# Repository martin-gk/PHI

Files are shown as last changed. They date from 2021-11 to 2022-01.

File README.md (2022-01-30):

# PHI - Plant Human Interface

Project for my bachelor thesis at FH JOANNEUM - Mobile Software Development

## Introduction

The Plant Human Interface project aims to bring the user closer to his houseplants. With the help of low entry hardware components like Arduino and the IOT, I plan to enhance myself to be able to feel when my houseplants needs to be watered.

## Motivation

Cyborgs have inspired the imagination of humans since the invention of machines. From dark dystopian futures like the Terminator or the BORG from Star Trek to helpful individuals like Inspector Gadget.
Our technological advancements have moved these fantasies into the realm of reality. Although one could argue that people with prosthetic limbs count as cyborgs, it does not satisfy this SciFi notion we have when we talk about cyborgs.
The following examples do however.

- [Neil Harbisson](https://en.wikipedia.org/wiki/Neil_Harbisson) with his [Eyeborg](https://en.wikipedia.org/wiki/Eyeborg)
- [Moon Ribas](https://en.wikipedia.org/wiki/Moon_Ribas) with her seismic sense
- The [North Sense](https://www.cyborgnest.net/northsense) from [Cyborg Nest](https://www.cyborgnest.net/) and their new product [Sentero](https://www.cyborgnest.net/sentero)
- [Kevin Warwick](https://en.wikipedia.org/wiki/Kevin_Warwick) and his countless experiments
- Everyone involved in the [Dangerous Things](https://dangerousthings.com/) community
- [Manel de Aguas](https://en.wikipedia.org/wiki/Manel_Mu%C3%B1oz) with his weather fins
- and many more

I myself am very fascinated by cyborgs and in awe of the technological possibilities at our hands. Therefore my project tries to make me a cyborg by enhancing my abilities and connecting me to a different organism - my houseplant -.

## Structure

The project is structured in five parts

- Plant
  - documentation for the microcontroller and sensors reading the plants vitals
  - how to assemble everything and the code needed to read the sensor values.
- Human
  - documentation on the hardware for the wearable
  - the code necessary to write data onto the e-paper display
  - the code necessary to use the vibrating motor
- Cloud
  - documentation on how to connect the devices to the IoT cloud
  - exemplary code on the auto generated sketches by the arduino IoT cloud
- Power
  - Information on different power sources as well as safety information
  - Recommendation on using a power bank
- Case
  - files for 3d printing a case

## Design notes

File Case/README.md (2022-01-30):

# 3d Case

If you have built the project so far, you may want <br>
to have a case in order to wear it comfortably. <br>
The files in this directory are always the same model, <br>
I just decided to export it in different formats <br>
in order to make it accessible to a multitude of 3d printers.<br>
<br>
As for the filament I used PA, but this is not required, please <br> just use whatever you have at hand.<br>
<br>
The small slit in the back of the case is for the vibration motor to <br>
slid through in order to have skin contact. <br>
As a recommendation I secured the ESP32 board via screws to the case.
After printing there is a small modification that I recommend you do.<br>
<br>
The red circle in the following picture shows where I drilled a hole <br>
on the side to pass the cables that go into the power bank through. <br><br>

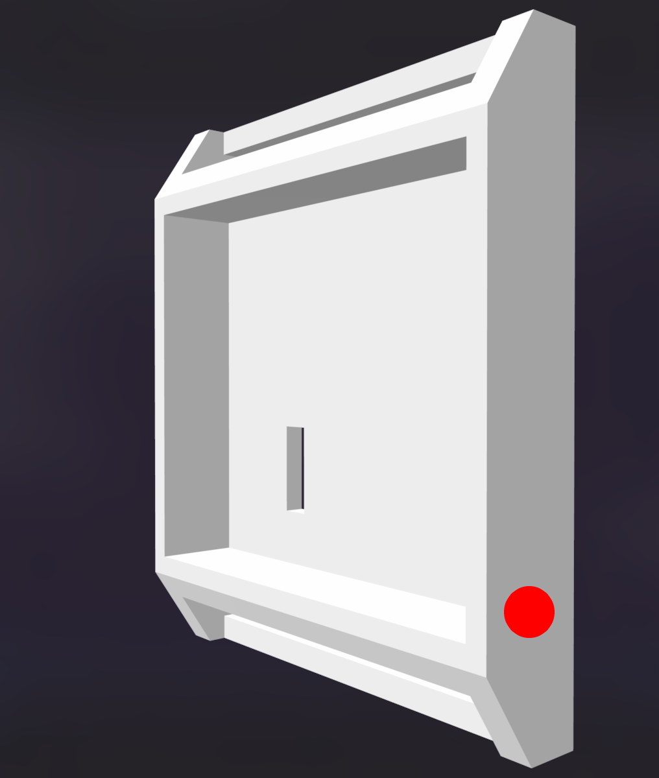
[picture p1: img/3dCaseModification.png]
3dcasemodification


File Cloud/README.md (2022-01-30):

# Cloud

## First Steps

The Arduino IoT Cloud is a service that is provided by Arduino. <br>
It features a free and a paid version. For the scope of this project the free version is enough <br>
but a registration is still necessary.

## Connect your hardware to the cloud

I will never be able to write a better step by step guide as Arduino themselves so please enjoy the wonderfully <br>
created tutorial by Arduino. <br>

- [Getting started with the Arduino IoT cloud](https://docs.arduino.cc/cloud/iot-cloud/tutorials/iot-cloud-getting-started)

When you have reached step 5 you will need to create the following variables

- humidity: float; Read and Write
- light: int; Read and Write
- temperature: float; Read and Write
- moisture: int; Read and Write

Once you have connected one device to the cloud you will want to sync the variables to the second device. <br>
This step is documented [here](https://docs.arduino.cc/cloud/iot-cloud/tutorials/device-to-device) in step 5.<br>
The tutorial features an explanation for arduino boards as well as for third party boards like the ESP32 for our wearable. <br>
Once you have completed all the steps the cloud will have generated a thingProperties.h sketch that your hardware needs in order to <br> communicate with the cloud. Exemplary sketches can be found in the directories inside this directory. <br>
The cloud will also generate a arduino_secrets.h file with your network login data. This is not included in this documentation.

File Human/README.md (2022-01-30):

# Human

## Hardware

- LILYGO TTGO E-Paper Watch
- T-U2T Downloader

## First Steps

As this is a complete system with the e-ink display and the vibrating motor already built in all you have to do is <br>
check if everything you ordered has been shipped. <br>
Especially the T-U2T Downloader as this is necessary to connect the board to your computer.

## Connecting to your computer

Connecting to your computer is simple. Just plugin the T-U2T Downloader into the board and then both via usb to your computer. <br>
For communication it may be that you will need to download drivers. <br>
Depending on which T-U2T Downloader you get the drivers are the following. <br>

- [cp210x](https://www.silabs.com/developers/usb-to-uart-bridge-vcp-drivers)
- [ch340k](http://wch-ic.com/products/CH340.html)
- [ch9102](http://www.wch.cn/products/CH9102.html) website is in chinese
- I found that on my newer windows machine the communication worked out of the box, without the need to install drivers

Depending on your previous experience in microcontroller you may also need to install the esp32 board to your Arduino IDE.<br>
Please refer to the following step by step guide on how to install esp32.

- [esp32 installation guide](https://randomnerdtutorials.com/installing-the-esp32-board-in-arduino-ide-windows-instructions/)

## Adding your hardware to the Arduino IoT cloud

This step will be covered in the cloud subsection of the project so please refer to it.

## Code

You will need to install the following extra libraries before you can compile your code.

- [Adafruit GFX](https://github.com/adafruit/Adafruit-GFX-Library) this library is easier to install with the built in library manager in the IDE
- [GxEPD lewisxhe fork](https://github.com/lewisxhe/GxEPD) Please note that you will need this fork. Download it as zip and import the zip file via your library manager.
- [u8g2 by Oli Kraus](https://github.com/olikraus/u8g2) This library can also be installed from within the library manager

The complete code is in this directory, everything of importance has been commented.<br>
Please don't forget that you will also need the thingProperties.h and the arduino_secrets.h generated by the arduino cloud in the <br> same directory for the project to work.

## Troubleshooting

IF you encounter the following error on compile

```
int16_t GxFont_GFX::getUTF8Width(const char*)' cannot be overloaded
error: with 'int16_t GxFont_GFX::getUTF8Width(const char*)
```

It is an error within the GxEPD library. You will need to go into the src code of the library and alter the following two files:

- GxFont_GFX.cpp: comment or delete line 68-71 and 285-288
- GxFont_GFX.h: comment or delete line 45 and 77

The issue is a merging error that has already been reported on the respective github repository.

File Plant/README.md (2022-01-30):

# Plant

## Hardware

- Arduino IOT Carrier
- Arduino MKR WIFI 1010
- Capacitive Soil Moisture Sensor v1.2

## First Step

We will be building this part of the project within the Arduino environment and with the Arduino IOT Cloud, so you will need to create an account on [arduino.cc](https://www.arduino.cc/).

After you have your account registered you need to connect the Arduino MKR WIFI 1010 onto the IOT Carrier.
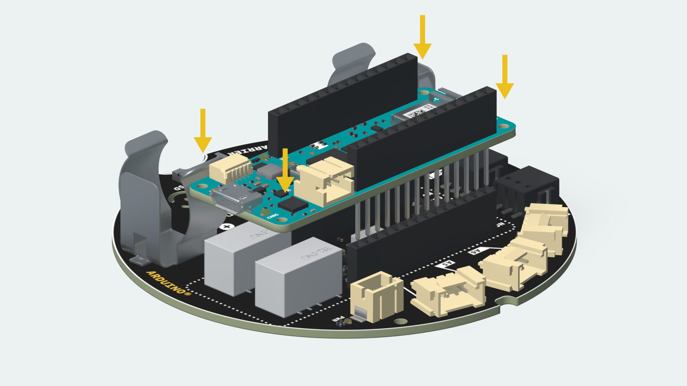
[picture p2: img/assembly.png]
assembly
[^1]
[^1]: Image taken from https://opla.arduino.cc/opla/module/carrier/lesson/discovering-the-mkr-iot-carrier
<br>

Please visit the [oplà kit website](https://opla.arduino.cc/opla/module/carrier/lesson/discovering-the-mkr-iot-carrier) for an in depth tutorial.

## Connecting to your computer

In order to be able to upload your first sketch onto your board, you will need to connect your board via USB to your computer.
You will need to download the [Arduino Create Agent](https://create.arduino.cc/getting-started/plugin/welcome) in order to recognize the Arduino boards and to read and write data from serial monitor.

You should be able to just use the Arduino Browser IDE but I also recommend downloading the standalone IDE. <br>
For example if you need to update the firmware, this will need to be done in the standalone IDE. <br>

## Adding your hardware to the Arduino IoT cloud

This step will be covered in the cloud subsection of the project so please refer to it.

## Code

The complete code is in this directory, everything of importance has been commented.
With your carrier connected via USB upload the sketch onto it. <br>
Once you have uploaded for the first time, the carrier supports Over the air uploads. <br>
This means you don't need to plug it in for updates, its enough to be in the same WiFi network.
<br>
Please don't forget that you will also need the thingProperties.h and the arduino_secrets.h generated by the arduino cloud in the <br> same directory for the project to work.

## Troubleshooting

If you get this error while trying to install your board to the cloud

```
MkrWifi1010 cannot connect to cloud
ArduinoIoTCloudTCP::handle_ConnectMqttBroker could not connect to mqtts-sa.iot.arduino.cc:8883
```

The firmware on your board is not up to date. <br>
Please refer to the following instruction to update the firmware. Be aware that you will need the freely available <br>
Arduino IDE for this step. <br>

- [Update MKR WiFi1010 Firmware guide](https://www.arduino.cc/en/Tutorial/WiFiNINA-FirmwareUpdater)

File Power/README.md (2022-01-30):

# Power

## Things to consider

- The wearable is run on 3.3V but can receive power from a source up to 5V.<br>
- Anything above and your board will be permanently damaged. <br>
- If your wearable does not receive enough power it will also not work.

## Possible power sources

Most of my information I gathered from the following website (link is in german)

- [Power ESP32 with battery](https://www.radioshuttle.de/media/tech-infos/esp32-mit-batteriebetrieb/)
  From that the solution that meets form, factor and our constraints mentioned above seems to be a LiPo battery. <br>
  This batteries are used in almost every wearable device that is in use nowadays. From mobile phones to e-cigarettes. <br>
  This is also a very cost inexpensive solution. <br>
  However there are also some drawbacks.

## Safety measures

LiPo batteries can become quite dangerous if they are not handled properly. <br>
If they overload or a cell gets damaged they can explode and cause a chemical fire. <br>
They should have safety circuitry built in but you never know the conditions they were made in. <br>
For that reason I have decided to use a power bank in my implementation of the project. <br>
It still uses a LiPo battery as a power source, but I have more faith in the manufacturing of a bigger brand than in my <br>
own soldering. Also the hard case around the cell feels more secure than having the naked battery directly on your skin.

## Connect the wearable to your battery

The LILYGO TTGO e-paper watch comes with a micro jst connector that ends in a red and black cable. <br>
To power the device you simply plug the jst connector into the female jst on your board. <br>
Now you need to connect this two wires onto your battery. <br>
If you decide to use a power bank like myself you will need to cut a USB cable and connect the black and red wires accordingly to <br> the wires attached to your board. <br>
Now you only need to plug the USB into your power bank and the wearable will be powered. <br>
Here is a picture of a cut USB cable, you only need the black and red wires, the other ones are data wires that can be cut short and ignored.
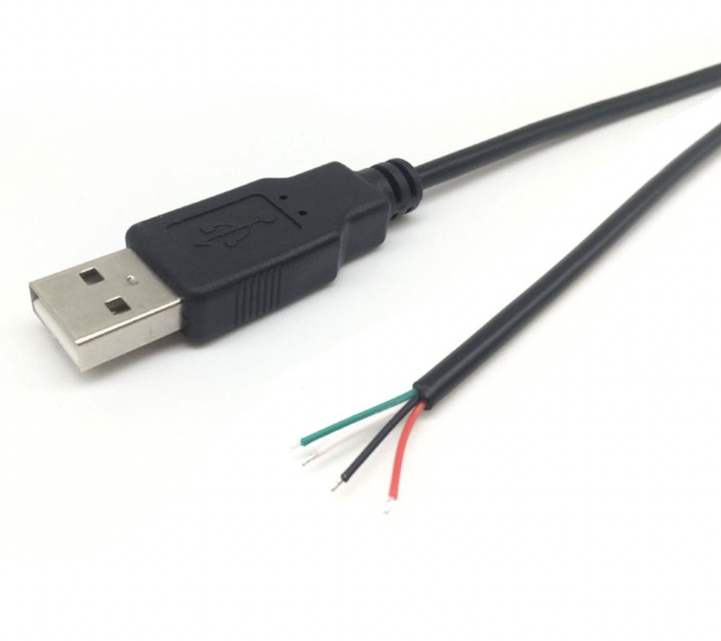
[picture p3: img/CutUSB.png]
USB


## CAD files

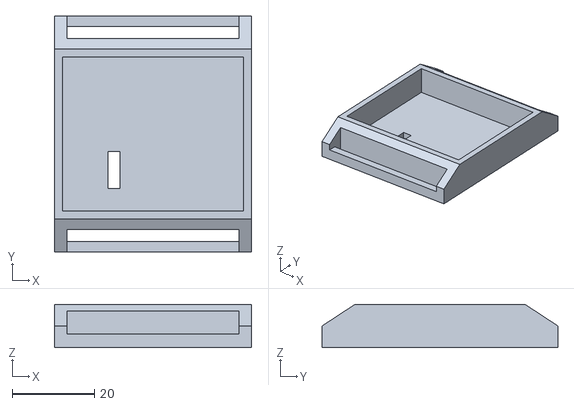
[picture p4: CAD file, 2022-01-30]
Case/PHI.stl
48.0 x 57.5 x 10.5

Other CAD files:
Case/PHI_druck_OSX.obj
Case/PHI_druck.obj
Case/PHI_druck.3dm
Case/PHI_druck.dwg
Case/PHI_druck.skp

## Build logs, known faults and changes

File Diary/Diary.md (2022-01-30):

### This document is just a loose list of my findings and issues as they come while working on the project

- Found out Arduino IOT Cloud does not support bluetooth boards. Kids thats why you carefully read the documentation first and don't just panic buy

  - there seems to be a workaround with IFTTT and the Adafruit Connect App

- Iphone seems to close BLE connection when locked. Hopefully it's just a scare. Need to check when I have actual code on my wearable. Again, read documentation first, cry later.

- Apparently I can't connect the vibration motors directly to the board. The board can be damaged. Why is electricity magic, and why can't I understand it?

  - "expensive" solution and complete overkill: [Haptic Motor Controller](https://www.adafruit.com/product/2305)
  - better solution [transistors](https://learn.adafruit.com/adafruit-arduino-lesson-13-dc-motors/transistors)
  - best solution have a board that comes with a vibrating motor

- There is plug-and-play and there is firmware updates. Wasted 3 hours and 2% hairs on a 10 min [fix](https://www.arduino.cc/en/Tutorial/WiFiNINA-FirmwareUpdater)

- Kids these day don't know how great they have it with autocomplete

- Compile error because your code is good but an imported library is not good is awful

- Sometimes you have to break your board in order to find out that what you have been looking for does not exist

- Compiling seconds are like hours in real time

- There is nothing like the helplessness of being unable to connect to your board

- shortcuts in your device communicator can ruin your life

- I hope its a shortcut

- Patience is a virtue you learn while waiting on your parts from china

- Comfort is not as important if you are afraid to loose your arm

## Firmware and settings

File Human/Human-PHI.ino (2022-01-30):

// add libraries

#include "arduino_secrets.h"
#include "thingProperties.h"
#include <GxEPD.h>
#include <GxDEPG0150BN/GxDEPG0150BN.h> // specific display inside the GxEPD library
#include <GxIO/GxIO_SPI/GxIO_SPI.h>    // specific folder inside the GxEPD library
#include <GxIO/GxIO.h>                 // specific folder inside the GxEPD library
#include <U8g2_for_Adafruit_GFX.h>     // font library

// define pin outs
#define PIN_MOTOR 4
#define PIN_KEY GPIO_NUM_35
#define PWR_EN 5

#define SPI_SCK 14
#define SPI_DIN 13
#define EPD_CS 15
#define EPD_DC 2
#define SRAM_CS -1
#define EPD_RESET 17
#define EPD_BUSY 16



GxIO_Class io(SPI, /*CS*/ EPD_CS, /*DC=*/EPD_DC, /*RST=*/EPD_RESET); // mapping of the defined pins to the GxIO class
GxEPD_Class display(io, /*RST=*/EPD_RESET, /*BUSY=*/EPD_BUSY);       // mapping of the defined pins to the GxEPD class
U8G2_FOR_ADAFRUIT_GFX u8g2Fonts;                                     // renaming for easier use





void setup() {
  // Initialize serial and wait for port to open:
  Serial.begin(9600);
  // This delay gives the chance to wait for a Serial Monitor without blocking if none is found
  delay(1500);

  // Defined in thingProperties.h
  initProperties();

  // Connect to Arduino IoT Cloud
  ArduinoCloud.begin(ArduinoIoTPreferredConnection);

  /*
     The following function allows you to obtain more information
     related to the state of network and IoT Cloud connection and errors
     the higher number the more granular information you’ll get.
     The default is 0 (only errors).
     Maximum is 4
  */
  setDebugMessageLevel(2);
  ArduinoCloud.printDebugInfo();

  Serial.println("ESP32 EPD Simple Test");
  SPI.begin(SPI_SCK, -1, SPI_DIN, EPD_CS);
  pinMode(PIN_MOTOR, OUTPUT);
  pinMode(PWR_EN, OUTPUT);

  digitalWrite(PWR_EN, HIGH);


  display.init();
  u8g2Fonts.begin(display);

}


void loop() {
  ArduinoCloud.update();
  
  u8g2Fonts.setFontMode(1);                           // use u8g2 transparent mode (this is default)
  u8g2Fonts.setFontDirection(0);                      // left to right (this is default)
  u8g2Fonts.setForegroundColor(GxEPD_BLACK);          // apply Adafruit GFX color black letters
  u8g2Fonts.setBackgroundColor(GxEPD_WHITE);          // apply Adafruit GFX color white background


  static int displayUpdater = 0;    /* static means that the variable will not be resetted every loop
                                       it saves its value */

  if (displayUpdater < 1) {         /* in order to save on energy consumption the display will only be updated every 5 minutes*/
    onMoistureChange();              // prepare info for display with the corresponding values 
    onLightChange();
    onTemperatureChange();
    display.update();                // update display
    displayUpdater = 100;            // reset counter for display updater
  }


  isThirsty();                      // is my plant thirsty
  isDying();                        // is my plant dying
  delay(3000);                      // delay the loop to only run every 3 seconds
  displayUpdater -= 1;              // decrease display counter

}


void isThirsty() {
  if (moisture < 15) return;        // if my moisture value is below 15 the plant is thirsty and the motor will not vibrate
  vibrateMotor();                   // if everything is ok the motor vibrates every 3 seconds 
}

void vibrateMotor() {
    digitalWrite(PIN_MOTOR, HIGH); // turn the motor on
    delay(100);
    digitalWrite(PIN_MOTOR, LOW);  // turn the motor off
}

void isDying() {                   // if the moisture levels are dangerous or the temperature is dangerous the motor will vibrate SOS in morse code
  if (temperature < 15 || temperature > 45 || moisture < 9 || moisture > 55) {
    vibrateSOS();
  }
}

void vibrateSOS() {
  for (int i = 0; i < 3; i++) { // three short bursts spelling the letter "S" in morse code
    digitalWrite(PIN_MOTOR, HIGH);
    delay(100);
    digitalWrite(PIN_MOTOR, LOW);
    delay(600);
  }
  for (int i = 0; i < 3; i++) { // three long bursts spelling the letter "O" in morse code
    digitalWrite(PIN_MOTOR, HIGH);
    delay(250);
    digitalWrite(PIN_MOTOR, LOW);
    delay(600);
  }
  for (int i = 0; i < 3; i++) {
    digitalWrite(PIN_MOTOR, HIGH);
    delay(100);
    digitalWrite(PIN_MOTOR, LOW);
    delay(600);
  }
}


void onLightChange()  {
  String lightAsString = String(light);
  u8g2Fonts.setFont(u8g2_font_helvR14_tf);            // select u8g2 font from here: https://github.com/olikraus/u8g2/wiki/fntlistall
  uint16_t x = display.width() / 2 + 55;              // define the x coordinate
  uint16_t y = display.height() / 2 + 70;             // define the y coordinate
  u8g2Fonts.setCursor(x, y);                          // start writing at this position
  u8g2Fonts.print(lightAsString);


  u8g2Fonts.setFont(u8g2_font_helvR10_tf);            
  x = display.width() / 2 + 45;
  y = display.height() / 2 + 90;
  u8g2Fonts.setCursor(x, y);                          
  u8g2Fonts.print("Light");
}


void onTemperatureChange()  {
  String tempAsString = String(temperature, 1);
  u8g2Fonts.setFont(u8g2_font_helvR14_tf);            
  uint16_t x = 20;
  uint16_t y = display.height() / 2 + 70;
  u8g2Fonts.setCursor(x, y);                          
  u8g2Fonts.print(tempAsString + "°C");


  u8g2Fonts.setFont(u8g2_font_helvR10_tf);            
  x = display.width() / 2 - 80;
  y = display.height() / 2 + 90;
  u8g2Fonts.setCursor(x, y);                          
  u8g2Fonts.print("Temp");
}


void onMoistureChange()  {
  String moistureAsString = String (moisture);
  u8g2Fonts.setFont(u8g2_font_inb53_mf);            
  uint16_t x = display.width() / 2 - 65 ;
  uint16_t y = display.height() / 2;
  display.fillScreen(GxEPD_WHITE);
  u8g2Fonts.setCursor(x, y);                          
  u8g2Fonts.print(moistureAsString + "%");


  u8g2Fonts.setFont(u8g2_font_helvR14_tf);            
  x = display.width() / 2 - 35;
  y = display.height() / 2 + 25;
  u8g2Fonts.setCursor(x, y);                          
  u8g2Fonts.print("Moisture");
}


//void onHumidityChange()  {
  /* The humidity variable is not necessary for this code, but since it is available from the cloud
     it was included should it be needed in the future */
//}

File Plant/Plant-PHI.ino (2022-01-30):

#include "thingProperties.h" //include generated sketch by the Arduino cloud
#include <Arduino_MKRIoTCarrier.h> //include the MKR IoT Carrier library
MKRIoTCarrier carrier;

int moistPin = A5; // declare pin

String lightState;

void setup() {
  // Initialize serial and wait for port to open:
  Serial.begin(9600);
  delay(1500);

  // Defined in thingProperties.h
  initProperties();

  // Connect to Arduino IoT Cloud
  ArduinoCloud.begin(ArduinoIoTPreferredConnection);
  //Get Cloud Info/errors , 0 (only errors) up to 4
  setDebugMessageLevel(2);
  ArduinoCloud.printDebugInfo();

  //Wait to get cloud connection to init the carrier
  while (ArduinoCloud.connected() != 1) {
    ArduinoCloud.update();
    delay(500);
  }

  delay(500);
  //update to true if you have the carrier in its case else use false
  CARRIER_CASE = true;
  carrier.begin();
  carrier.display.setRotation(0);
  delay(1500);
}

void loop() {
  //Update the Cloud
  ArduinoCloud.update();

  //read temperature and humidity
  temperature = carrier.Env.readTemperature();
  humidity = carrier.Env.readHumidity();

  //read raw moisture value
  int raw_moisture = analogRead(moistPin);

  //map raw moisture to a scale of 0 - 100
  moisture = map(raw_moisture, 0, 1023, 100, 0);

  //read ambient light, the units for measurement are LUX
  while (!carrier.Light.colorAvailable()) {
    delay(5);
  }
  int none; //We are not interested in light color just light intensity
  carrier.Light.readColor(none, none, none, light);

  delay(100);

}
